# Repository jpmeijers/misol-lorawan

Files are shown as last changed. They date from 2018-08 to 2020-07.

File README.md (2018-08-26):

# LoRa Weather Station

__THIS IS STILL A WORK IN PROGRESS__

This repo contains a design for a replacement PCB for a MISOL weather station. The replacement PCB fits in the same space and enclosure as the original transmitter board. It sends the sensor data via a LoRa radio. The new PCB supports LoRaWAN and can send the data to a network like The Things Network.

The PCB design is done using KiCad.

# References

http://www.misolie.net/weather-station-c-43.html

https://www.robotics.org.za/WH-SP-WS02

https://www.sparkfun.com/products/8942

https://cdn.sparkfun.com/assets/8/4/c/d/6/Weather_Sensor_Assembly_Updated.pdf

# Original PCB

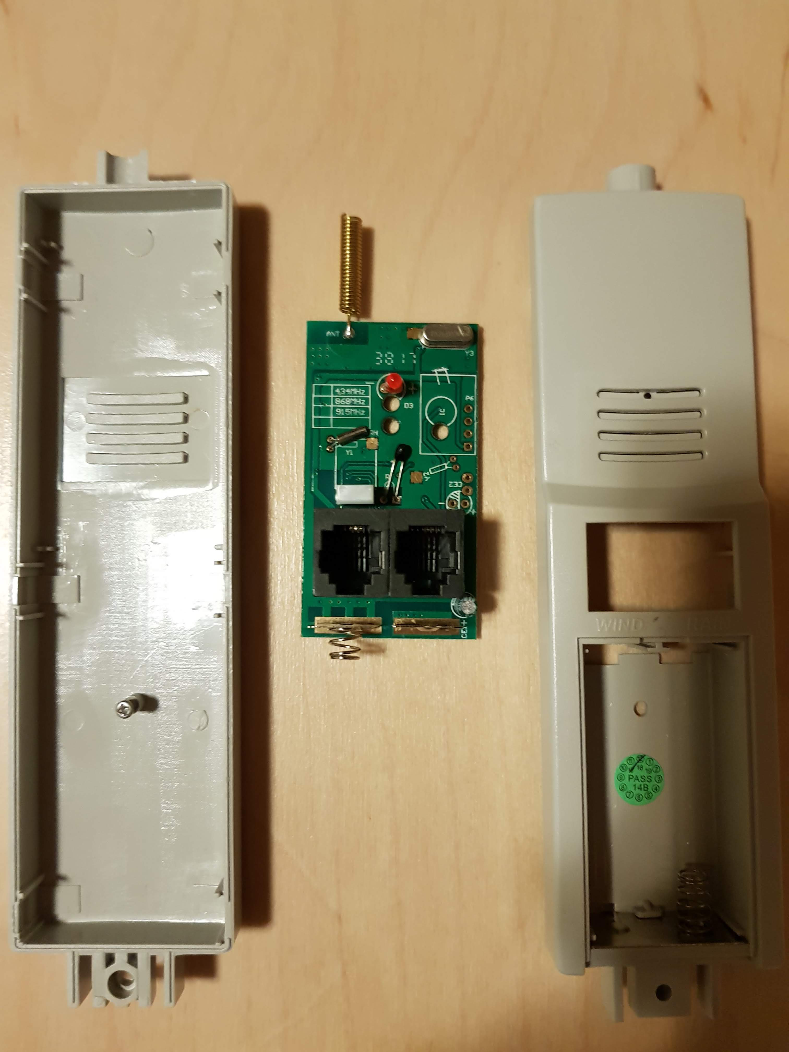
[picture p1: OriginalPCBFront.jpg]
Original front Front


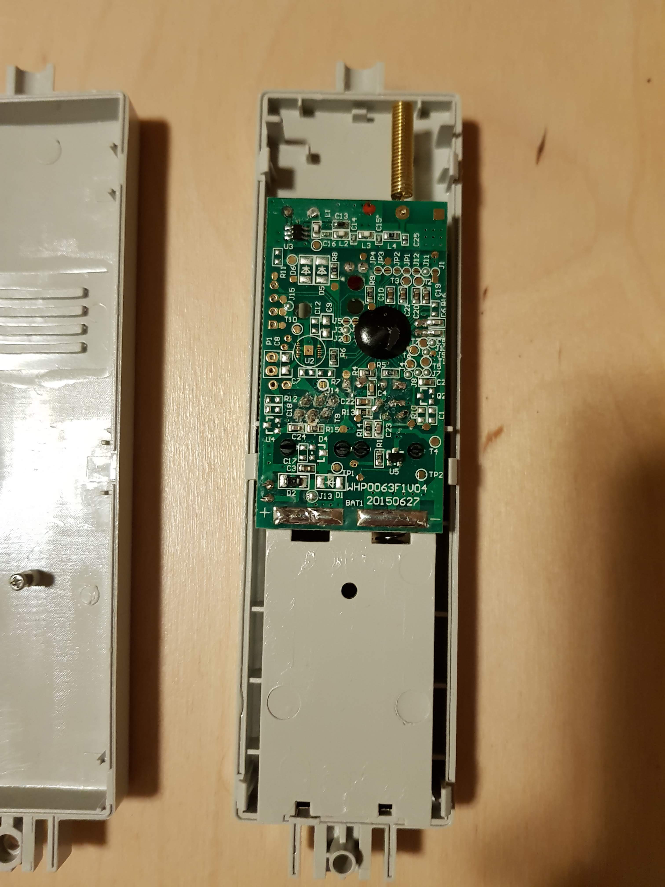
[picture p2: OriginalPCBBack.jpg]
Original back Back


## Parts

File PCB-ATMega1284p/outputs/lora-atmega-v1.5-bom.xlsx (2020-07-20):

Designator | Quantity | Package | Description | Comment | LCSC Part Number(optional) | Manufacture Part Number | Manufacturer(optional) | URL
U2 | 1 | NiceRF LoRa | RFM95 |  |  | LORA1276-C1-868 | NiceRF | https://www.nicerf.com/product_146_198.html
U3 | 1 | TQFP-44_10x10mm_Pitch0.8mm | ATMEGA1284P-AU |  | C33575
D1 | 1 | LED_D3.0mm | LED |  | C99771
U1 | 1 | BME280 | BME280 |  | C92489
Y1 | 1 | Crystal_SMD_0603-4Pin_6.0x3.5mm | Crystal_GND24 |  | C133333
J1,J4 | 2 | SPARKFUN_RJ11-6 | WIND,RAIN |  | C305971
C1,C2,C3,C5,C6,C10,C12,C13,C14,C15 | 10 | C_0805_2012Metric | 100n | any cheapest option is ok
C4,C11 | 2 | C_0805_2012Metric | 10u | any cheapest option is ok
C7 | 1 | C_0805_2012Metric | 1pF | any cheapest option is ok
C8,C9 | 2 | C_0805_2012Metric | 22p | any cheapest option is ok
L1 | 1 | L_0805_2012Metric | 12nH |  | C75651
R1,R2,R3,R4,R5 | 5 | R_0805_2012Metric | 10k | any cheapest option is ok
L2 |  |  |  | DO NOT SOLDER
J6,J7,J8,J9,J10,J5 |  |  |  | DO NOT SOLDER
J2 |  |  |  | DO NOT SOLDER
J3 |  |  |  | DO NOT SOLDER
AE1 |  |  |  | DO NOT SOLDER
J11 |  |  |  | DO NOT SOLDER
J12 |  |  |  | DO NOT SOLDER
J13 |  |  |  | DO NOT SOLDER

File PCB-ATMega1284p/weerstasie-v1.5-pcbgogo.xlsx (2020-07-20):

Designator | Quantity | Package | Description | TH or SMD or not soldered | Comment | LCSC Part Number(optional) | Manufacture Part Number | Manufacturer(optional) | URL
U2 | 1 | NiceRF LoRa | RFM95 | SMD |  |  | LORA1276-C1-868 | NiceRF | https://www.nicerf.com/product_146_198.html
U3 | 1 | TQFP-44_10x10mm_Pitch0.8mm | ATMEGA1284P-AU | SMD |  | C33575
D1 | 1 | LED_D3.0mm | LED | TH |  | C99771
U1 | 1 | BME280 | BME280 | SMD |  | C92489
Y1 | 1 | Crystal_SMD_0603-4Pin_6.0x3.5mm | Crystal_GND24 | SMD |  | C133333
J1,J4 | 2 | SPARKFUN_RJ11-6 | WIND,RAIN | TH |  | C305971
C1,C2,C3,C5,C6,C10,C12,C13,C14,C15 | 10 | C_0805_2012Metric | 100n | SMD | any cheapest option is ok
C4,C11 | 2 | C_0805_2012Metric | 10u | SMD | any cheapest option is ok
C7 | 1 | C_0805_2012Metric | 1p | SMD | any cheapest option is ok
C8,C9 | 2 | C_0805_2012Metric | 22p | SMD | any cheapest option is ok
R1,R2,R3,R4,R5 | 5 | R_0805_2012Metric | 10k | SMD | any cheapest option is ok
L1 | 1 | L_0805_2012Metric | 12nH | SMD |  | C75651
L2 |  |  |  | DO NOT SOLDER
J6,J7,J8,J9,J10,J5 |  |  |  | DO NOT SOLDER
J2 |  |  |  | DO NOT SOLDER
J3 |  |  |  | DO NOT SOLDER
AE1 |  |  |  | DO NOT SOLDER
J11 |  |  |  | DO NOT SOLDER
J12 |  |  |  | DO NOT SOLDER
J13 |  |  |  | DO NOT SOLDER

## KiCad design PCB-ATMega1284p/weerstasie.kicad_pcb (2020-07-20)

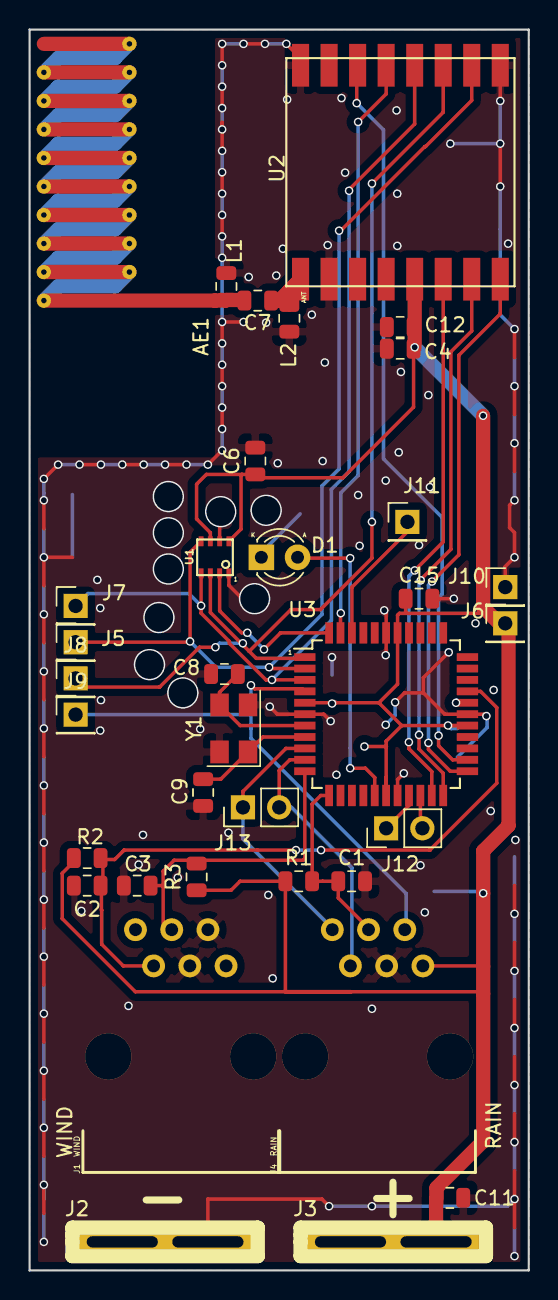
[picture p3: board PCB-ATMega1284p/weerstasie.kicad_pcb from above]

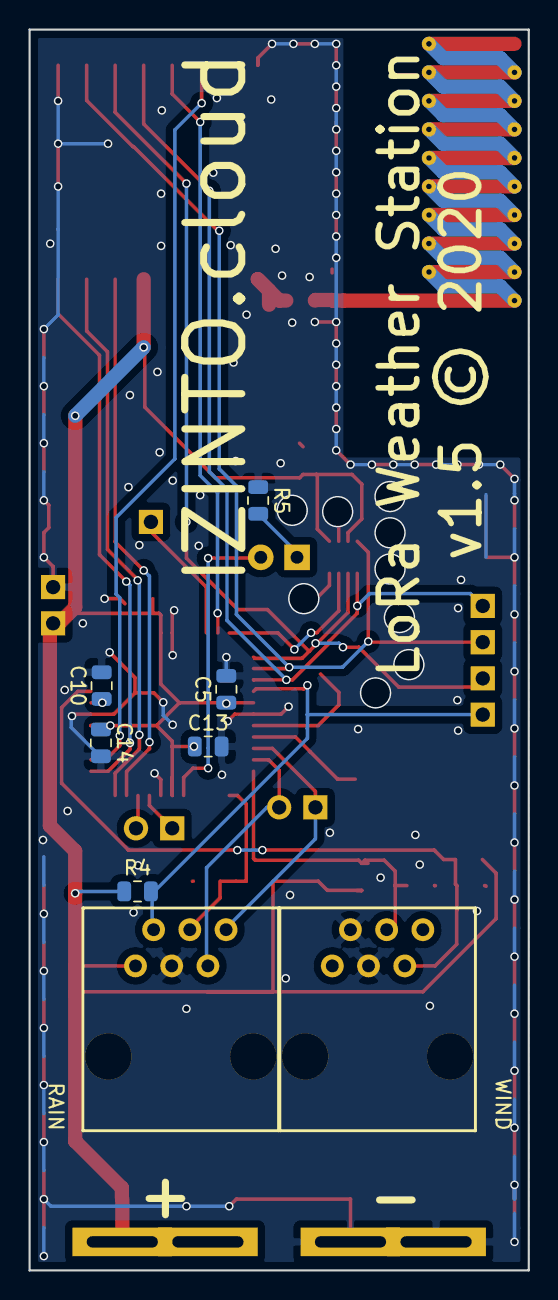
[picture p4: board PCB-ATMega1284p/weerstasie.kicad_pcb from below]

Board: 2 copper layers, 35.0 x 87.0 mm, 41 parts (6 on the bottom side), 27 nets.

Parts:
AE1: Antenna; PCB_HELICAL_ANTENNA_868
C1, C2, C3, C5, C6, C10, C12, C13, C14, C15: 100n; C_0805_2012Metric
C4, C11: 10u; C_0805_2012Metric
C7: 1pF; C_0805_2012Metric
C8, C9: 22p; C_0805_2012Metric
D1: LED; LED_D3.0mm
J1: WIND; TE_Connectivity_5520425-3
J2: batt -; BATTERY_TERMINAL
J3: batt +; BATTERY_TERMINAL
J4: RAIN; TE_Connectivity_5520425-3
J5, J6, J7, J8, J9, J10: Conn_01x01; Pin_Header_Straight_1x01_Pitch2.54mm
J11: INT2; Pin_Header_Straight_1x01_Pitch2.54mm
J12: I2C; Pin_Header_Straight_1x02_Pitch2.54mm
J13: UART; Pin_Header_Straight_1x02_Pitch2.54mm
L1: 12nH; L_0805_2012Metric
L2: NA; L_0805_2012Metric
R1, R2, R3, R4, R5: 10k; R_0805_2012Metric
U1: BME280
U2: RFM95
U3: ATMEGA1284P-AU; TQFP-44_10x10mm_Pitch0.8mm
Y1: Crystal_GND24; Crystal_SMD_5032-4Pin_5.0x3.2mm

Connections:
/BME_SS: U1.2, U3.44
/MISO: J5.1, U1.5, U2.2, U3.2
/MOSI: J8.1, U1.3, U2.3, U3.1
/RAIN: C1.1, J4.3, R1.2, U3.12
/RESET: J4.5, J9.1, R4.2, U3.4
/RFM_D0: U2.14, U3.21
/RFM_D1: U2.15, U3.22
/RFM_D2: U2.16, U3.23
/RFM_RESET: U2.6, U3.24
/RFM_SS: U2.5, U3.43
/SCK: J7.1, U1.4, U2.4, U3.3
/UART_RX: J4.1, J13.1, U3.9
/UART_TX: J4.2, J13.2, U3.10
/WIND_DIR: C2.1, J1.2, R2.2, U3.30
/WIND_SPEED: C3.1, J1.3, R3.2, U3.11
GND: C1.2, C2.2, C3.2, C4.2, C5.2, C6.2, C8.2, C9.2, C10.2, C11.2, C12.2, C13.2, C14.2, C15.2, J1.4, J1.5, J1.7, J1.8, J2.1, J4.4, J4.7, J4.8, J10.1, L1.1, L2.1, R5.1, U1.1, U1.7, U2.1, U2.8, U2.10, U3.6, U3.18, U3.28, U3.39, Y1.2, Y1.4
unnamed: AE1.1, C7.2, L1.2
unnamed: C7.1, L2.2, U2.9
unnamed: C8.1, U3.7, Y1.3
unnamed: C9.1, U3.8, Y1.1
unnamed: C10.1, U3.29
unnamed: D1.1, R5.2
unnamed: D1.2, U3.16
unnamed: J11.1, U3.42
unnamed: J12.1, U3.19
unnamed: J12.2, U3.20
VCC: C4.1, C5.1, C6.1, C11.1, C12.1, C13.1, C14.1, C15.1, J3.1, J4.6, J6.1, R1.1, R2.1, R3.1, R4.1, U1.6, U1.8, U2.13, U3.5, U3.17, U3.27, U3.38

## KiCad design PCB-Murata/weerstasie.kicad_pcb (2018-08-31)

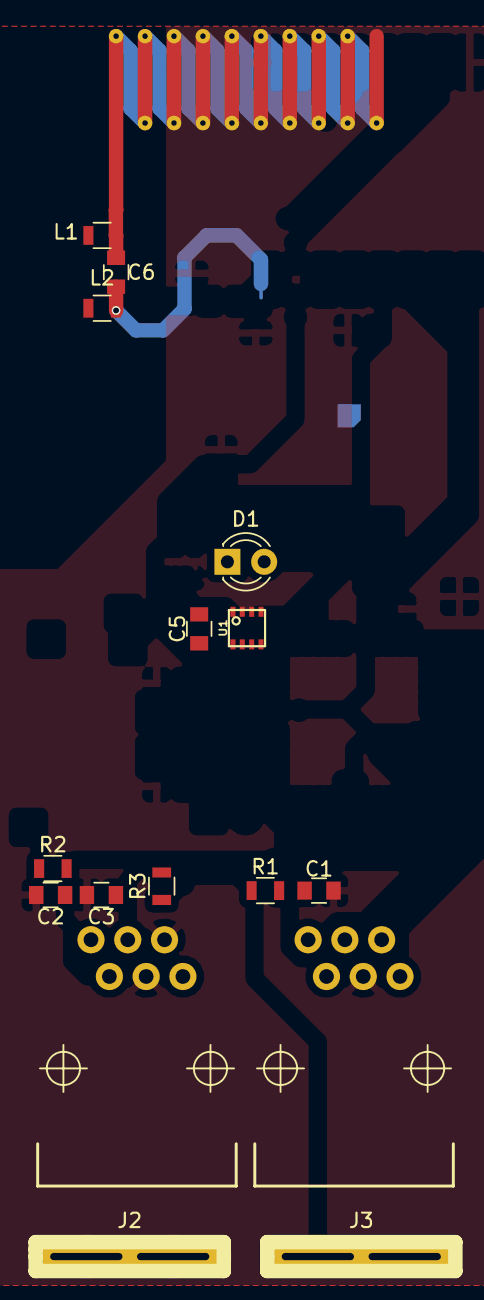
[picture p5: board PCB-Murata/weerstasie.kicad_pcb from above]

Board: 2 copper layers, 18 parts (1 on the bottom side), 15 nets.

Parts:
AE1: Antenna; PCB_HELICAL_ANTENNA_868
C1, C2, C3, C5: 100n; C_0805
C6: 1pF; C_0805
D1: LED; LED_D3.0mm
J1: WIND; SPARKFUN_RJ11-6
J2: batt -; BATTERY_TERMINAL
J3: batt +; BATTERY_TERMINAL
J4: RAIN; SPARKFUN_RJ11-6
L1: 12nH; L_0805
L2: NA; L_0805
R1: 10k1; R_0805
R2: 10k2; R_0805
R3: 10k3; R_0805
U1: BME280
U2: CMWX1ZZABZ-078; XCVR_CMWX1ZZABZ-078

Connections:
/ANT_MCU: C6.1, L2.2, U2.26
/BME_SS: U1.2, U2.17
/MISO: U1.5, U2.15
/MOSI: U1.3, U2.14
/RAIN: C1.1, J4.3, R1.2, U2.42
/SCK: U1.4, U2.16
/SOLAR_1: J4.1, U2.33
/SOLAR_2: J4.2, U2.24
/SOLAR_5: J4.5, U2.23
/SOLAR_6: J4.6, U2.22
/WIND_DIR: C2.1, J1.2, R2.2
/WIND_SPEED: C3.1, J1.3, R3.2, U2.41
GND: C1.2, C2.2, C3.2, C5.2, J1.4, J1.5, J2.1, J4.4, L1.1, L2.1, U1.1, U1.7, U2.3, U2.7, U2.25, U2.27, U2.44, U2.49, U2.50, U2.51, U2.52, U2.53, U2.54, U2.55, U2.56, U2.57
unnamed: AE1.1, C6.2, L1.2
VCC: C5.1, J3.1, R1.1, R2.1, R3.1, U1.6, U1.8

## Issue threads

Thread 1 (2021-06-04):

Request for info - not as issue

bwims, 2021-06-04:
Hello,

sorry to trouble you, but you are the only person I know who has this unit.  Would you be so kind as to include measurements of the PCB and the external case?   I want to implement a solution using a different board, and I'd like to know if it will fit in the stevenson shield.  What I'd really like to do is 3d print an empty case that would fit all of the standard brackets and stevenson screen.

Thanks for taking the time to read this!

Brian Williams

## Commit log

2018-08-26 Add images of the original pcb
2018-08-26 Add missing connections in schematic
    [weerstasie.kicad_pcb, weerstasie.sch]
2018-08-27 Ready to be routed
    [weerstasie.kicad_pcb, weerstasie.sch]
2018-08-31 Finish PCB layout and rename
    [weerstasie.kicad_pcb, weerstasie.sch]
2018-08-31 Copy design and replace ATmega and RFM95 with Murata LoRa module
    [_saved_weerstasie.sch, weerstasie.kicad_pcb, weerstasie.sch]
2018-09-01 Some PCB cleanup
    [weerstasie.kicad_pcb]
2018-09-01 Some starting connections for murata
    [_saved_weerstasie.sch, weerstasie.sch]
2018-09-01 More cleanup and comaptibility with allpcb
    [weerstasie.kicad_pcb, weerstasie.sch]
2018-09-01 Include Gerbers as ordered from AllPCB
    [weerstasie-B.Cu.gbr, weerstasie-B.Mask.gbr, weerstasie-B.SilkS.gbr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]
2018-09-01 Add ventilation holes/vias around thermometer and resend gerbers to AllPCB
    [weerstasie-B.Cu.gbr, weerstasie-B.Mask.gbr, weerstasie-B.SilkS.gbr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]
2019-02-20 Update to kicad 5 Move rj11's closer together
    [weerstasie-2019-02-20-09-13-12.sch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]
2019-05-27 Fix RJ11 solder mask. Add v1.4 label. Order from JLC.
    [weerstasie.kicad_pcb, weerstasie.sch]
2020-07-18 Remove solar connections. Add uart on rain rj12.
    [weerstasie.kicad_pcb]
2020-07-20 Misol Lora Atmega V1.5 order placed with PCBgogo
    [lora-atmega-v1.5-bom.xlsx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]

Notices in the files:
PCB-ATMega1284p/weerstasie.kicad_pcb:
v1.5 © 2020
